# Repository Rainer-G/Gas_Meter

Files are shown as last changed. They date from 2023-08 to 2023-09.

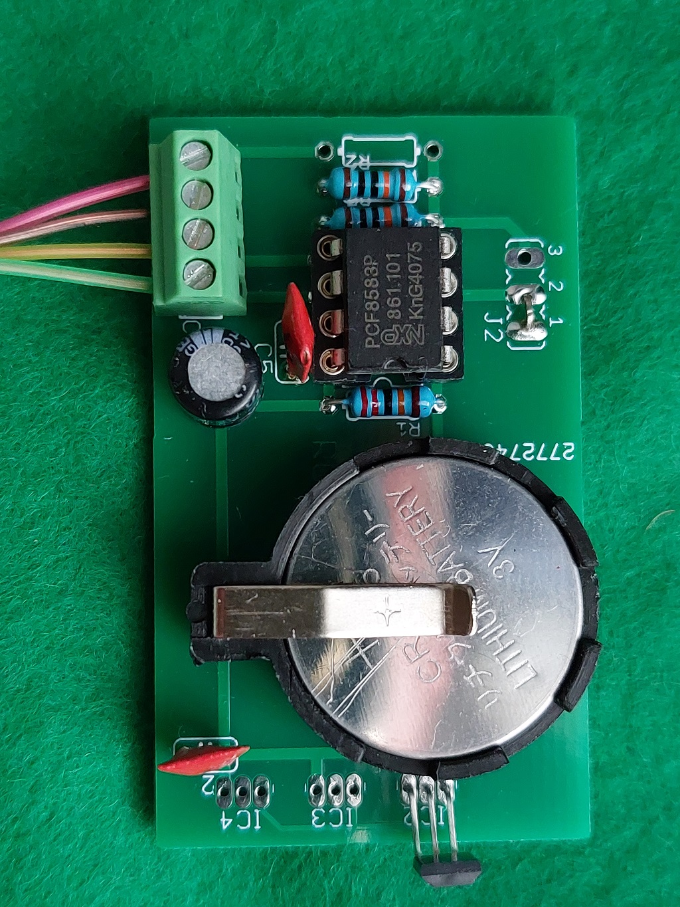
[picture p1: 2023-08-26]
Gas_Meter/pcb/CP Gas Zähler Lesekopf1.jpg

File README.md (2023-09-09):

# Gas Verbrauch messen und verarbeiten 

## Funktion

Manche Gaszähler geben pro vebrauchte 10 Liter einen magnetischen Impuls ab.
Dieser Impuls wird mit einem Hall Sensor in elektrische Impulse gewandelt, ein RTC Baustein PCF8583 arbeitet als Zähler und speichert die Zahl der Impulse im internen RAM ab.

PCB Eagle Dateien und Stückliste anbei.

Die Daten werden mit Hilfe eines ESP8266 über die I²C SAchnittstelle ausgelesen und verarbeitet. 
Über das MQTT Protokoll werden die Daten an einen lokalen Broker weitergeleitet, Daten werden nicht ins Internet hochgeladen.
Eine 3 Volt Knopfzelle versorgt den Baustein mit Energie und erhält die Daten bei Stromausfall.

* Diese Daten werden im RTC RAM gespeichert

1. Zählimpulse
2. Zählerstand zu Beginn der Messung ( Counts = 0 )
3. Zählerstand zu Beginn der Abrechnungsperiod
4. monatlicherVerbrauch in m³
5. Datum und Uhrzeit des letzen Auslesens des RTC Bausteins

* Diese Daten werden über MQTT an den Broker gesendet

1. Uhrzeit 
2. Gesamtverbrauch in kWh
3. Verbrauch zwischen zwei Zugriffen auf den RTC Speicher in kWh
4. Anzahl der Impulse seit Reset
5. Gesamtverbrauch in m³
6. Zählerstand zum Begin der Messung ( Counts = 0 ) in Liter
7. Zählerstand zum Begin der Abrechnungsperiode in Liter
8. nach Bedarf monatlicher Verbrauch
9. Status ( OK wenn Zugriff auf den RTC Baustein möglich )

* Diese Daten/Kommandos können vom Broker an den ESP8266 gesendet werden

1. Publish consumption of a single month or month 1 to 12 
 * SYNTAX  : "Energy/Test/command"
 * PAYLOAD : "Month, x"
 * value for x : either 1 to 12 for a single month, x > 12 shows all 12 months
  
 2. Set consumption for the start of a heating period 
 * SYNTAX  : "Energy/Test/command"
 * PAYLOAD : "InitP, x"
 * value for x : consumption in liter

 3. Set initial consumption value for a count value of zero 
 * SYNTAX  : "Energy/Test/command"
 * PAYLOAD : "InitS, x"
 * value for x : consumption in liter

 4. Set consumption for a single month to init data  
 * SYNTAX  : "Energy/Test/command"
 * PAYLOAD : "InitM, x ; y"
 * value for x : selected month
 * value for y : consumption in liter
 
 5. Set consumption for the start of a counting period 
 * Initialyse RTC chip and set initial consumption value for count = 0 of a counting period 
 * SYNTAX  : "Energy/Test/command"
 * PAYLOAD : "InitC, x"
 * value for x : consumption in liter

## Vorbereitung

* in Gas_WiFi SSID und Passwort eintragen
* in Gas_MQTT IP Adresse des MQTT Broker eintragen
* ggfs. Thinkspeak aktivieren und Channel und Key eintragen
* Topic für MQTT an die eigenen Wünsche anpassen

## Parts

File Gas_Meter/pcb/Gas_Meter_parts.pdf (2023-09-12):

Gas Zähler
Stückliste und Board
Part | Value | Device | Package
C1 | 47µF | CPOL-EUE2.5-5 | E2,5-5
C2 | 10nF | C-EU025-024X044 C025-024X044
C5 | 10nF | C-EU025-024X044 C025-024X044
GND | Note(1) | 2,54/1,0 | 2,54/1,0
IC1 | PCF8583P | PCF8583P | DIL08
IC2 | AH3661UA | AH3661UA | SIP3-UA
IC3 | Note(2)
IC4 | Note(2)
J2 | Note(3) | JP2E | JP2
R1 | 470k | R-EU_0204/7 | 0204/7
R2 | 220k | R-EU_0204/7 | 0204/7
R3 | 10k | R-EU_0204/7 | 0204/7 | ( optional )
R5 | 220k | R-EU_0204/7 | 0204/7
VDD | Note(1) | 2,54/1,0 | 2,54/1,0
X2 | | MPT4 | 4POL254

Note(1)
VDD / GND sind Anschlusspads für eine CR2032 Batterie Halter

Note(2)
Hall Sensor AH3661UA ( bipolar, low Power, VCC ab 2,4 Volt ) nur 1 mal an passender Stelle einsetzen

Note(3)
Jumper 2 wählt die Adresse des PCF8583
Brücke 1—2 : Adresse 0x50

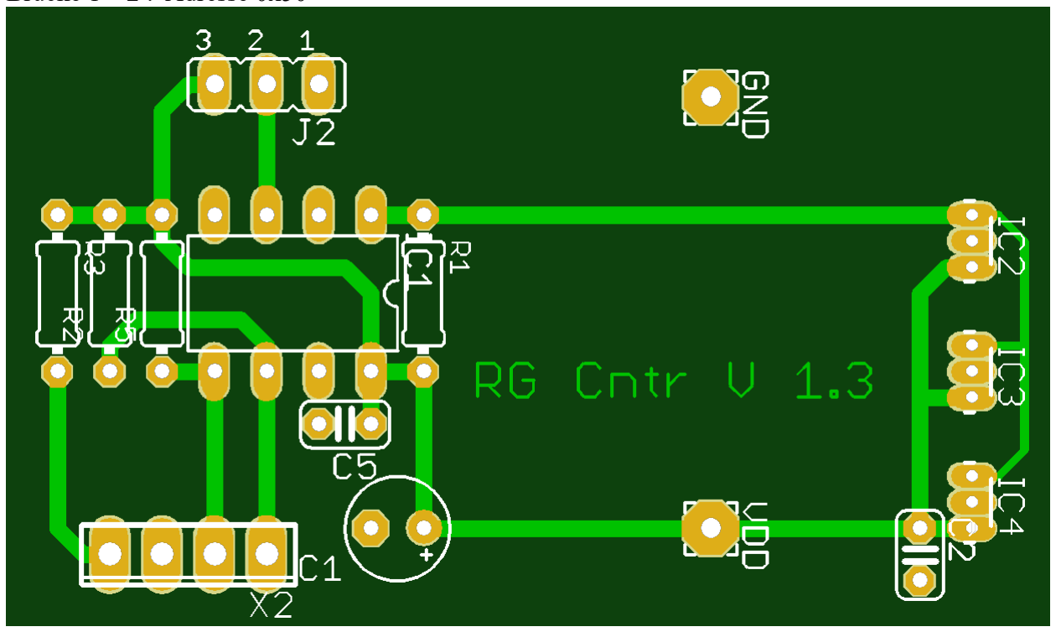
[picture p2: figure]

V | G S | S
D | N D C
D | D A | L

Zusammenbau

Alle Bauteile werden von der bedruckten Seite bestückt

Zunächst die Widerstände, dann C2 und C2, sinnvollerweise eine IC Fassung für IC1, dann C1 und X2.

Sichtprüfung, erst dann der Batteriehalter, Polarität beachten!

Nun probeweise eine CR2032 Zelle einsetzen, Spannung an der IC Fassung messen, Pin 4 muss auf GND liegen, an Pin 8 muss die Versorgungsspannung VDD anliegen, die muss auch an Pin 1 zu finden sein, ebenso an dem Pin 1 des Hall Sensors, durch den Spannungsabfall an R1 wird diese Spannung dort etwas niedriger auls an Pin 8 von IC1, das hängt vom Innenwiderstand des Messgerätes ab!

CR2032 wieder entfernen, Hall Sensor an der passenden Stelle einlöten. Die richtige Stelle ist die, die bei eingesetzter Platine genau unter der 1ner Stelle des Zählers sitzt.
Das Löten ist hier wegen der geringen Abstände der Anschlussdrähte etwas kniffelig, Lötzinn sparsam einsetzen, am Besten ist hier 0,5 mm Durchmesser des Lötdrahtes!
Anschlussdrähte etwa 1 cm zwischen Sensor und Platine lassen, damit der Sensor in die richtige Position am Platinenrand gebracht werden kann.

CR2032 probeweise wieder einsetzen, Spannung am Pin 1 von IC1 messen, mit einem Magneten sich dem Sensor nähern, die Spannung muss auf etwa Null Volt sinken und wieder auf VDD steigen, wenn der Magnet wieder entfernt wird.

CR2032 wieder entfernen und IC1 einsetzen, CMOS Bausteine erfordern Schutz gegen statische Aufladen!

Die Knopfzelle wieder einsetzen, an SDA und SCL muss VDD anliegen.

Einen ESP8266 entsprechend anschließen und mit einem I²C Scanner den RTC Baustein suchen, er sollte auf der Hex Adresse 50 zu finden sein.

Falls kein I²C Scanner vorhanden ist, kann auch das Leseprogramm verwendet werden, es sollte über den seriellen Monitor Fehlermeldung ausgeben, wenn der RTC Baustein nicht gefunden wird.

Gegenfalls Verdrahtung von SDA, SCL und GND prüfen.

Bemerkung:

R1 kann entfallen, es sei denn, die Elektronik wird durch eine externe 3 Volt Batterie, 3,6 Volt LiIon Batterien gehen auch, allerdings muss der ESP8266 diese Spannung auch an den SCL / SDA Anschlüssen vertragen!

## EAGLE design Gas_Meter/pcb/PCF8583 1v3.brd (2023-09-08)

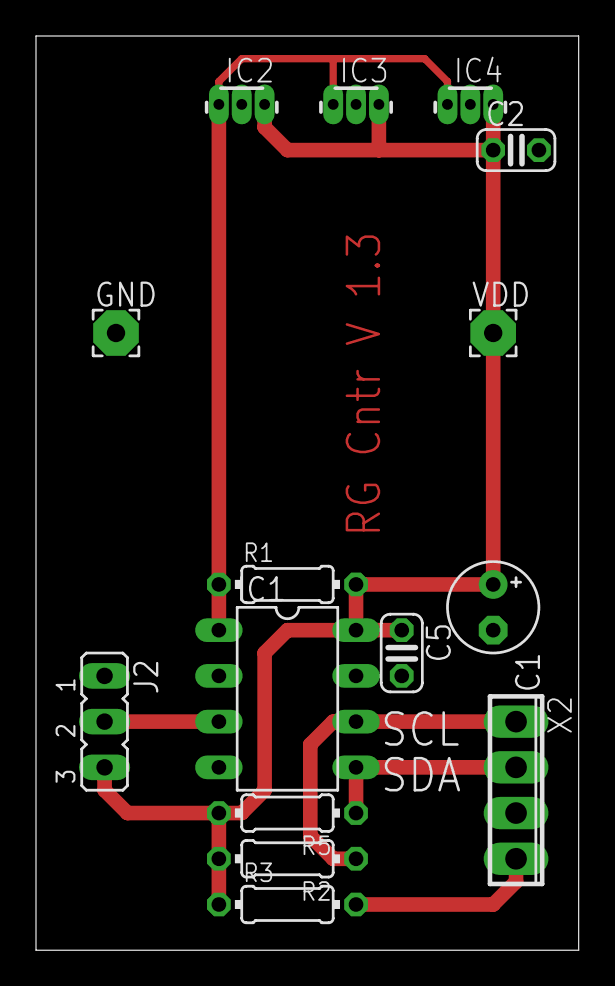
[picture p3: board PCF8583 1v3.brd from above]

Board: 2 copper layers, 30.1 x 50.8 mm, 15 parts (0 on the bottom side), 7 nets.

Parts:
C1: 47µF; E2,5-5
C2, C5: 10nF; C025-024X044
GND: 2,54/1,0
IC1: PCF8583P; DIL08
IC2, IC3, IC4: A1301UA; SIP3-UA
J2: JP2
R1: 470k; 0204/7
R2, R5: 220k; 0204/7
R3: 10k; 0204/7
VDD: 2,54/1,0
X2: 4POL254

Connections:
CNT: IC1.1, IC2.3, IC3.3, IC4.3, R1.1
GND: C1.-, C2.2, C5.2, GND.1, IC1.4, IC2.2, IC3.2, IC4.2, J2.1, X2.3
unnamed: R3.2, X2.4
unnamed: IC1.3, J2.2
SCL: IC1.6, R2.1, X2.1
SDA: IC1.5, R5.1, X2.2
VDD: C1.+, C2.1, C5.1, IC1.8, IC2.1, IC3.1, IC4.1, J2.3, R1.2, R2.2, R3.1, R5.2, VDD.1

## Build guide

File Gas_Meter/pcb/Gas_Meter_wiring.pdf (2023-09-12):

ESP8266 Wiring Diagram

Connect the fully assembled RTC PCB to SDA,SCL,GND of the ESP8266, insert coin cell CR2032. Do not connect the VDD terminal on the PCB.

To initialize the RTC Chip, connect GPIO13 ( D7 on WEMOS S1 mini ) to ground. Reset the ESP8266 and the RTC Init routine will be called in the setup function and the programm loop. Remove the connection once the init is done.

The init procedure has to be repeated after power loss of the CR2032 battery.

If you want to send MQTT commands to a sleeping ESP8266, connect GPIO12 ( D6 on WEMOS S1 mini ) to GND and wait for next wake up. Send the required commands, watch the execution on an MQTT Explorer and remove the connection once all commands are properly executed.

WEMOS D1 mini Top View
RTC
Reset | RST | | TX | TXD
Analog IN | A0 | | RX | RXD
GPIO16 | D0 | | D1 | GPIO05 | SCL
GPIO14 | D5 | ESP8266 | D2 | GPIO04 | SDA
UPDATE_PIN | GPIO12 | D6 | D3 | GPIO00
RESET_PIN | GPIO13 | D7 | D4 | GPIO02
GPIO15 | D8 | | GND | | GND
3,3 Volt | 3V3 | | 5 V
| | USB
Connect GPIO12 to GND to temporarily prevent sleep and allow MQTT to send commands Connect GPIO12 to GND to reset the ESP and the RTC IC
Connect GPIO16 to RST to wake up from deep sleep

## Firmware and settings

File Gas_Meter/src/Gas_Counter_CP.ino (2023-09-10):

/**************************************************************************/
/*
  Use RTC as counter and read results with TWI
  Store last value in RAM
*/
/**************************************************************************/
//#define THINGSPEAK                                 // if you want send data to the Internet

#include <Wire.h>
#include "Gas_WiFi.h"
#include "Gas_MQTT.h"
#include "Gas_Time.h"
#ifdef THINGSPEAK
  #include "Gas_Thingspeak.h"
#endif  
//
#define RESET_PIN            D7                             // LOW will reset the counter and clear old data
#define UPDATE_PIN           D6                             // LOW will prevent going to sleep, needed for MQTT Commands & OTA updates
//
#define COUNTER_MODE         0x20                           // counter mode 0x20  
#define COUNTER_ADDRESS      0x50                           // 7 I²C bit address for RTC Chip
// address locations
#define CONTROL_ADDRESS      0x00
#define ADDRESS_COUNTER      0x01                           // only 3 bytes with 6 BCD digits
// starting from 0x10, we have 240 bytes of RAM for free use
#define RAM_OFFSET           0x10                           // start after reserved RAM locations
#define ADDRESS_OLD_COUNTER  RAM_OFFSET                     // provide 4 bytes
#define ADDRESS_OLD_TIME     ADDRESS_OLD_COUNTER   + 4      // provide 4 bytes
#define ADDRESS_OLD_DATE     ADDRESS_OLD_TIME      + 4      // provide 4 bytes
#define ADDRESS_START_METER  ADDRESS_OLD_DATE      + 4      // provide 4  bytes for meter data at first start 
#define ADDRESS_START_PERIOD ADDRESS_START_METER   + 4      // provide 4  bytes for meter data for start of period
#define ADDRESS_MONTH_01     ADDRESS_START_PERIOD  + 4      // provide 4  bytes for meter data at month end of first month of period
#define NEXT_FREE_ADDRESS    ADDRESS_MONTH_01      + ( 4 * 12 )  
//
//**********************************************************************************
// connect D0 to RST if you want sleep
// using D6 for controlling Sleep Mode
//**********************************************************************************
//
bool      sleep                = false;//true;             // allow sleep
bool      error                = false;            // report error to MQTT
bool      log_msg              = true;             // for Test only, set to false when in operation
uint32_t  old_time;                                // in seconds
uint8_t   old_date[ 3 ];                           // year, month, day
uint32_t  new_time;                                // in seconds
uint8_t   new_date[ 3 ];                           // year, month, day
uint32_t  old_count            = 0;
uint32_t  new_count            = 0;
uint32_t  delta_count          = 0;
uint32_t  liter_per_count      = 10;               // see meter label
float     mexp3_per_count      = 0.01;             // see meter label
double    brennwert            = 11.53800;
double    zustandszahl         = 0.93940;
uint16_t  year_offset          = 2000;
float     energy1              = 0;                // current load in kWh  : Gas m³ * Brennwert * Zustandszahl
double    total_energy         = 0;                // total usage  in kWh  : Gas m³ * Brennwert * Zustandszahl
uint32_t  start_consumption    = 0;                // set after first start or battery change
double    consumption          = 0;                // Gas in liter
uint32_t  start_period         = 0;                // Gas in liter
uint32_t  period               = 0;                // in seconds
uint32_t  consumption_data     = 0;                // value for a monthly consumption
String    consumption_string   = "";               // temp string for a monthly consumption
uint8_t   month_data           = 0;                // month for above
uint32_t  temp_data            = 0;
//char      valueString[ 80 ];
char      valueString1[ 80 ];
char      valueString2[ 80 ];
char      valueString3[ 80 ];
char      valueString4[ 80 ];
char      valueString5[ 80 ];
char      valueString6[ 80 ];
char      valueString7[ 80 ];
char      valueString8[ 80 ];
//char      valueString9[ 80 ];
//char      valueString10[ 80 ];
//char      valueString11[ 80 ];
uint8_t   old_year;
uint8_t   old_day;
uint8_t   old_month;
uint8_t   old_hour;
uint8_t   old_min;
uint8_t   old_sec;
//
//  for data transfer
//
union     long_t
{
  uint32_t long_data;
  uint8_t  byte_data[ 4 ];
};
union     int_t
{
  uint16_t int_data;
  uint8_t  byte_data[ 2 ];
};
//
//
uint8_t bcd2byte( uint8_t value )
{
  return (( value >> 4 ) * 10 ) + ( value & 0x0f );
}

uint8_t byte2bcd( uint8_t value )
{
  return (( value / 10) << 4 ) + ( value % 10 );
}


bool set_Counter_Mode( )
{
  Wire.beginTransmission( COUNTER_ADDRESS );

  Wire.write( CONTROL_ADDRESS );
  Wire.write( COUNTER_MODE );
  return ( Wire.endTransmission( true ) == 0 );
}

uint8_t get_Mode( )
{
  return get_Byte( CONTROL_ADDRESS );
}

bool set_Byte( int8_t address, int8_t value )
{
  Wire.beginTransmission( COUNTER_ADDRESS );
  Wire.write( address );
  Wire.write( value );
  return ( Wire.endTransmission( true ) == 0 );
}

int8_t get_Byte( int8_t address )
{
  Wire.beginTransmission( COUNTER_ADDRESS );
  Wire.write( address );
  Wire.endTransmission( );
  Wire.requestFrom( COUNTER_ADDRESS, 1 );
  return Wire.read( );
}

bool set_Integer( int8_t address, int16_t value )
{
  int_t  temp_data;
  temp_data.int_data = value;
  Wire.beginTransmission( COUNTER_ADDRESS );
  Wire.write( address );
  Wire.write( temp_data.byte_data[ 0 ] );
  Wire.write( temp_data.byte_data[ 1 ] );
  return ( Wire.endTransmission( true ) == 0 );
}

bool get_Integer( int8_t address, int16_t &value )
{
  int_t  temp_data;
  
  value = 0;
  Wire.beginTransmission( COUNTER_ADDRESS );
  Wire.write( address );
  Wire.endTransmission( );
  byte len = Wire.requestFrom( COUNTER_ADDRESS, 2 );
  if ( len == 0 )
  {
    Serial.println("");
    Serial.println("***************** Error occured when reading 2 bytes ******************");
    return false;
  }
  else
  {
    temp_data.byte_data[ 0 ] = Wire.read( );
    temp_data.byte_data[ 1 ] = Wire.read( );
    value                    = temp_data.int_data;
    return true;
  }
}

bool set_My_4_bytes( int8_t address, int32_t value )
{
  union long_t  temp_data;
  int8_t  result = 9;
  temp_data.long_data = value;
  Wire.beginTransmission( COUNTER_ADDRESS );
  Wire.write(  address );
  Wire.write(  temp_data.byte_data[ 0 ] );
  Wire.write(  temp_data.byte_data[ 1 ] );
  Wire.write(  temp_data.byte_data[ 2 ] );
  Wire.write(  temp_data.byte_data[ 3 ] );
  return ( Wire.endTransmission( true ) == 0 );
}


bool get_My_4_bytes( int8_t address, uint32_t &value )
{

  long_t  temp_data;

  value = 0;

  Wire.beginTransmission( COUNTER_ADDRESS );
  Wire.write( address );
  Wire.endTransmission( );
  byte len = Wire.requestFrom( COUNTER_ADDRESS, 4 );
  if ( len == 0 )
  {
    Serial.println("");
    Serial.println("********************* Error occured when reading My 4 bytes **************");
    return false;
  }
  else
  {
    temp_data.byte_data[ 0 ] = Wire.read( );
    temp_data.byte_data[ 1 ] = Wire.read( );
    temp_data.byte_data[ 2 ] = Wire.read( );
    temp_data.byte_data[ 3 ] = Wire.read( );
    value            = temp_data.long_data;
    return true;
  }
}

bool get_Counter( int8_t address, uint32_t &count  )
{
  count = 0;
  Wire.beginTransmission( COUNTER_ADDRESS );               // stored as BCD digits in 3 bytes
  Wire.write( address );
  Wire.endTransmission( );
  byte len = Wire.requestFrom( COUNTER_ADDRESS, 3);

  if (len == 0)
  {
    Serial.println("");
    Serial.println("********************* Error occured when reading Counter *****************");
    return false;
  }
  else
  {
    count =         bcd2byte( Wire.read( ));
    count = count + bcd2byte( Wire.read( )) * 100L;
    count = count + bcd2byte( Wire.read( )) * 10000L;
    return true;
  }
}

bool set_Counter( int8_t address, int32_t value )            // store as BCD digits in 3 bytes
{
  Wire.beginTransmission( COUNTER_ADDRESS );
  Wire.write( address );
  Wire.write( byte2bcd(   value % 100L ));
  Wire.write( byte2bcd( ( value / 100L ) % 100L ));
  Wire.write( byte2bcd( ( value / 10000L ) % 100L ));
  return ( Wire.endTransmission( true ) == 0 );
}

void get_Time( int8_t address, uint8_t &o_hour, uint8_t &o_min, uint8_t &o_sec )    // return 3 hex bytes
{

  Wire.beginTransmission( COUNTER_ADDRESS );
  Wire.write( address );
  Wire.endTransmission( );
  Wire.requestFrom( COUNTER_ADDRESS, 3 );

  o_hour   = Wire.read( );         // get Hour
  o_min    = Wire.read( );         // get minute
  o_sec    = Wire.read( );         // get second

}

bool set_Time( int8_t address, uint8_t o_hour, uint8_t o_min, uint8_t o_sec )            // store as 3 hex bytes
{
  Wire.beginTransmission( COUNTER_ADDRESS );
  Wire.write( address );
  Wire.write( o_hour );
  Wire.write( o_min  );
  Wire.write( o_sec  );
  return ( Wire.endTransmission( true ) == 0 );
}

void get_Date( int8_t address, uint8_t &day, uint8_t &month, uint8_t &year )
{
  uint8_t value;

  Wire.beginTransmission( COUNTER_ADDRESS );
  Wire.write( address  );
  Wire.endTransmission();
  Wire.requestFrom( COUNTER_ADDRESS, 3 );

  day   = Wire.read( );                       // get day
  month = Wire.read( );                       // get month
  year  = Wire.read( ) + year_offset;         // get year

}

bool set_Date( int8_t address, uint8_t day, uint8_t month, int year )
{
  uint8_t value;

  Wire.beginTransmission( COUNTER_ADDRESS );
  Wire.write( address  );
  Wire.write( day ) ;
  Wire.write( month );
  year = year - year_offset ;
  Wire.write( year );
  return ( Wire.endTransmission( true ) == 0 );

}

bool set_month( int8_t month, int32_t new_count ) 
{
   uint8_t  month_address     = 0;
   uint32_t month_consumption = 0;
    
   month_address      = ADDRESS_MONTH_01  + ( month - 1 ) * 4;            // calculate address for current month
   month_consumption  = start_consumption + new_count * liter_per_count ; // up to date consumptiion
   return set_My_4_bytes( month_address, month_consumption );
}

int32_t get_month( int8_t month ) 
{
   uint8_t  month_address     = 0;

   month_address      = ADDRESS_MONTH_01  + ( month - 1 ) * 4;            // calculate address for current month
   if ( get_My_4_bytes( month_address, temp_data ) != true ) temp_data = 0 ;
   return temp_data;
}

//
//**************************************************************************************************
//                                          L O G P R I N T                                        *
//**************************************************************************************************
// Log messages if log_msg is true                                                                 *
// Uses vsnprint for format strings, needs /r/n for CR/LF at end                                   *
//**************************************************************************************************
//
char* logprint ( const char* format, ... )
{
  static char sbuf[ 128 ] ;                            // For debug lines
  va_list     varArgs ;                                // For variable number of params

  va_start ( varArgs, format ) ;                       // Prepare parameters
  vsnprintf ( sbuf, sizeof(sbuf), format, varArgs ) ;  // Format the message
  va_end ( varArgs ) ;                                 // End of using parameters
  if ( log_msg )                                       // Log Messages on ?
  {
    Serial.print ( sbuf ) ;                            // and the info
  }
  return sbuf ;                                        // Return stored string
}

//
// Init RTC Counter
//
void Init_counter( )
{
  logprint( "***  Set Counter Mode *******" );
  if ( set_Counter_Mode( ) == false )
     logprint( "***  failed to set Counter Mode *******");        // only needed for first init
  logprint( "***  Clear counter data *******" );
  if ( set_Counter    ( ADDRESS_COUNTER, 0 ) == false )
     logprint( "***  Failed to clear counter *******");           // do not clear counter after reset
  if ( set_My_4_bytes ( ADDRESS_OLD_COUNTER, 0 ) == false )
     logprint( "***  Failed to clear old counter data *******");  // do not clear counter after reset
  //set_My_4_bytes ( ADDRESS_START_METER, 0 );                   // do not clear start consumption after reset
  logprint( "***  Clear Time *******" );
  set_Time       ( ADDRESS_OLD_TIME, 0, 0, 0 );
  //
  // init old time
  //
  logprint( "***  Set Time *******" );
  set_Time( ADDRESS_OLD_TIME, Gas_hour, Gas_min, Gas_sec ); //
  //
}
//
// MQTT commnands
//

void publish_month( )                        // send consumption data for selectetd month

{
   uint8_t  cmd_month = 0;
   uint8_t  cmd_value = 0;
   uint8_t  cmd_start = 0;
   uint8_t  cmd_end   = 0;
   uint32_t cmd_data  = 0;
   String   value3;

   consumption_string = MQTT_command.substring( MQTT_command.indexOf(',') + 1); 
   cmd_value          = consumption_string.toInt();
   cmd_month          = constrain( cmd_value, 1, 12 );
   value3             = ""; 

   if ( cmd_value  <= 12 )            // inside the 1 to 12 limit?
   {
      cmd_start = cmd_month;
      cmd_end   = cmd_month;
   }
   else
   {
      cmd_start = 1;
      cmd_end   = 12;
   }
   for ( int i = cmd_start; i <= cmd_end; i++ )
   {
      get_My_4_bytes( ( ADDRESS_MONTH_01  + ( i - 1 ) * 4 ), cmd_data );
      value3 = value3  + ';' + String( i ) + ';' + String( cmd_data );
   }
   publish_topic( "month_data", value3 );
   
   MQTT_command  = "";
}   
//
void set_period( )                           // set start value for heating period

{
   uint32_t cmd_data  = 0;
   String   value3;
   
   if ( MQTT_command.indexOf(',') > 0 )
   {
      value3    = MQTT_command.substring( MQTT_command.indexOf(',') + 1); 
      cmd_data  = value3.toInt();
   }
   if ( set_My_4_bytes( ADDRESS_START_PERIOD, cmd_data ) == false )
   {
      logprint( "Failed to save Start Period %10d\n\r", MQTT_command );
   }
 
   MQTT_command = "";

}

void set_start( )                           // set start value for heating period

{
   uint32_t cmd_data  = 0;
   String   value3;
   
   if ( MQTT_command.indexOf(',') > 0 )
   {
      value3    = MQTT_command.substring( MQTT_command.indexOf(',') + 1); 
      cmd_data  = value3.toInt();
   }
   if ( set_My_4_bytes( ADDRESS_START_METER, cmd_data ) == false )
   {
      logprint( "Failed to save Start Period %10d\n\r", MQTT_command );
   }
 
   MQTT_command = "";

}

void init_counter_and_data( )                           // set start value for counting and set count = 0

{
   uint32_t cmd_data  = 0;
   String   value3;
   
   Init_counter( );
  
   if ( MQTT_command.indexOf(',') > 0 )
   {
      value3    = MQTT_command.substring( MQTT_command.indexOf(',') + 1); 
      cmd_data  = value3.toInt();
   }
  //
  //   save start consumption frm MQTT to RAM
  //
  if ( cmd_data >= 0 )
  {
     if ( set_My_4_bytes( ADDRESS_START_METER, cmd_data ) == false )
     {
        logprint( "Failed to save Start Consumption %10d\n\r", MQTT_command );
     }
  }
 
   MQTT_command = "";

}
void set_month_data( )                          // set data for a comsumption month

{
   uint32_t cmd_data    = 0;
   uint8_t  cmd_month   = 0;
   uint8_t  cmd_address = 0;
   String   value2;
   String   value3;
 
   value2    = MQTT_command.substring( MQTT_command.indexOf(',') + 1); 
   cmd_month = value2.toInt();
  
   if (( MQTT_command.indexOf(',') > 0   ) &&
       ( cmd_month                       > 0   ) &&
       ( cmd_month                       <= 12 ))
   {
      cmd_data     = 0; 
      if ( MQTT_command.indexOf(';') > 0 )
      {
         value3    = MQTT_command.substring( MQTT_command.indexOf(';') + 1); 
         cmd_data  = value3.toInt();
      }  
      cmd_address  = ADDRESS_MONTH_01  + ( cmd_month - 1 ) * 4;            // calculate address for current month
      set_My_4_bytes( cmd_address, cmd_data );
//      logprint( "Saving %14d to Month %02d at address %08d\n\r", cmd_data, cmd_month, cmd_address );
  }  
   //
   // 
   publish_month( );
   delay( 3000 );
   // 
   MQTT_command = "";

}

void command_parser()
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
void loop()
{
   mqtt.loop();
   error = false;           // reset error flag
  //
  // check WiFi connection
  //
  if ( WiFi.status() != WL_CONNECTED )
    Gas_WiFi_reconnect();
  //
  // parse MQTT commands
  //
  if ( MQTT_command != "" ) command_parser ();
  //
  // read current time from ESP
  //
  get_LocalTime( );
  logprint( "Datum %02d.%02d.%04d Uhrzeit  %02d:%02d:%02d\n\r", Gas_day, Gas_month, Gas_year, Gas_hour, Gas_min, Gas_sec );
  //
  //   read current counter from counter location
  //
  if ( get_Counter( ADDRESS_COUNTER, new_count ) != true ) 
  {
     error     = true;
     new_count = 0;                  // to do
  }   
  //
  //   read old counter from RAM
  //
  if ( get_My_4_bytes( ADDRESS_OLD_COUNTER, old_count ) != true ) old_count = 0 ;
  //
  logprint( "***  New Count %10d Old Count %10d\n\r", new_count, old_count );

  //
  //   get start consumption
  //
  if ( get_My_4_bytes( ADDRESS_START_METER, start_consumption ) != true ) start_consumption = 0 ;
  //
  //   get period consumption
  //
  if ( get_My_4_bytes( ADDRESS_START_PERIOD, start_period ) != true ) start_period = 0 ;
  //
  //   save current counter to RAM
  //
  if ( set_My_4_bytes( ADDRESS_OLD_COUNTER, new_count ) == false )
  {
    logprint( "Failed to save New to Old Count ***  New Count %10d Old Count %10d\n\r", new_count, old_count );
  }
  //
  // read last time
  //
  get_Time( ADDRESS_OLD_TIME, old_hour, old_min, old_sec );
  //
  // save Date & time of current read  in RAM
  // TO DO check whether period per read or per xmitt success
  if ( set_Time( ADDRESS_OLD_TIME, Gas_hour, Gas_min, Gas_sec ) == false )
  {
    logprint( "Failed to save New to Time ***  New Time %02d:%02d:$02d\n\r", Gas_hour, Gas_min, Gas_sec );
  }
  //
  // read date of last readoute
  get_Date( ADDRESS_OLD_DATE, old_day, old_month, old_year );
  //
  // save data for current month
  //
  if ( set_month( Gas_month, new_count) == false )
  {
    logprint( "Failed to save mmonthly data Gas_month %02d New Count:%06d\n\r", Gas_month, new_count );
  }
  //
  //
  set_Date( ADDRESS_OLD_DATE, Gas_day, Gas_month, Gas_year );
  // calculate period between 2 reads
  period =   ( Gas_hour - old_hour ) * 3600L +
             ( Gas_min  - old_min  ) *   60  +
             ( Gas_sec  - old_sec );
  new_time = ( Gas_hour ) * 3600L +
             ( Gas_min  ) *   60  +
             ( Gas_sec  );
  old_time = ( old_hour ) * 3600L +
             ( old_min  ) *   60  +
             ( old_sec );
  //
  logprint( "Old Time %02d:%02d:%02d New Time %02d:%02d:%02d Period %10d\n\r",
             old_hour, old_min, old_sec, Gas_hour, Gas_min, Gas_sec, period );
  logprint( "Old Time %08d New time %06d  in secondes\n\r", old_time, new_time );
  // calculate counts between two read outs
  delta_count       = new_count - old_count;
  //
  // calculate absolute consumption bewteen two reads
  //
  energy1      = ( mexp3_per_count * brennwert * zustandszahl * delta_count )      ; // in kWh  : Gas m³ * Brennwert * Zustandszahl
  total_energy = ( mexp3_per_count * brennwert * zustandszahl * new_count )        ; // in kWh  : Gas m³ * Brennwert * Zustandszahl
  consumption  = ( start_consumption + new_count * liter_per_count ) / 1000.0      ; // up to date consumptiion
  
  dtostrf( total_energy,     12, 3, valueString1 );
  dtostrf( energy1,          12, 3, valueString2 );
  dtostrf( consumption,      12, 3, valueString3 );
  dtostrf( new_count,        10, 0, valueString4 );
  //dtostrf( new_time,         10, 0, valueString6 );
  //dtostrf( old_time,         10, 0, valueString7 );
  dtostrf( ( 3600L / ( new_time - old_time ) * energy1 ),  12, 3, valueString5  );
  dtostrf( ( start_consumption / 1000.0 ),                 12, 3, valueString6  );
  dtostrf( ( start_period / 1000.0 ),                      12, 3, valueString7 );
  sprintf( valueString8, "%02d:%02d:%02d", Gas_hour, Gas_min, Gas_sec );
  //
  // calculate consumption per hour or minute
  //
#ifdef THINGSPEAK 
{
   //
   // write data to the ThingSpeak channel
   //
   ThingSpeak.setField( Thingspeak_1, valueString1 );            // total consumption
   ThingSpeak.setField( Thingspeak_2, valueString2  );           // consumption between two readouts
   ThingSpeak.setField( Thingspeak_4, valueString4  );           // total counts 
   ThingSpeak.setField( Thingspeak_5, valueString3  );           // Gas m³
   // send data to Thingspeak fields
   Send_data( );
}
#endif
 
  //if ( old_min != Gas_min )
  {  
  //
  // publish to MQTT
  //
    publish_topic( "Time", valueString8 );
    publish_topic( "Total_kWh", valueString1 );
    publish_topic( "Power_kW", valueString5 );
    publish_topic( "Counts", valueString4 );
    publish_topic( "Volume", valueString3 );
    publish_topic( "Start", valueString6 );
    publish_topic( "Period_Start", valueString7 );
    if ( error == true )
      publish_topic( "Status", "Error" );
    else
      publish_topic( "Status", "OK" );
  //
  }  
  //
  //  check if Sleep or wait
  //
  if ( digitalRead( UPDATE_PIN ) == 1 )      // pull UPDATE ptin LOW to prevent sleep
  {
    logprint( "Going to sleep\n" );
    delay( 1000 );
    ESP.deepSleep( 111 * 1000 * 1000 );
  }
  else
  {
    logprint( "Waiting 30 seconds\n" );
    delay( 30000 );
  }
}

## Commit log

2023-09-08 Update README.md
    Funktion und Daten ergänzt
2023-09-08 Added text for Jumper J2
    [PCF8583 1v3.sch]
2023-09-10 Bug Fix in Init
    [Gas_Counter_CP.ino]
